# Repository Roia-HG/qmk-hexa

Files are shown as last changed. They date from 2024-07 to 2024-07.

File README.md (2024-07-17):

# qmk-hexa

 RP2040 칩을 사용한 멀티배열 스플릿 키보드

 3d 모델은 마그네틱 포고핀과 결합하는 구멍간격을 잘못 측정해서(데이터가 없었던 걸로 기억함) 개선이 필요함
그대로 사용하면 나처럼 한쪽을 약간 잘라서 사용해야하는 불상사가 일어남

 메인 오른쪽은 왼쪽 마그네틱 포고핀과 선을 연결하지 않음
양쪽 메인이 접속되면 row열 신호에 혼란이 발생하여 오류가 생길 것이기 때문에 스위치를 설치하는 것도 생각했지만
스위치를 설치할 적절한 방법이 떠오르지 않고 귀찮았으므로 연결하지 않고 사용하는 것으로 진행
즉, 메인 왼쪽은 네비키와 넘패드키 모두 좌우로 장착 가능하지만 메인 오른쪽은 오른쪽에만 장착 가능함.



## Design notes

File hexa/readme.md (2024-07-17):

# hexa

hexa

*A short description of the keyboard/project*

* Keyboard Maintainer: [Geon](https://github.com/Roia-HG)
* Hardware Supported: *The PCBs, controllers supported*
* Hardware Availability: *Links to where you can find this hardware*

Make example for this keyboard (after setting up your build environment):

    make hexa:default

Flashing example for this keyboard:

    make hexa:default:flash

See the [build environment setup](https://docs.qmk.fm/#/getting_started_build_tools) and the [make instructions](https://docs.qmk.fm/#/getting_started_make_guide) for more information. Brand new to QMK? Start with our [Complete Newbs Guide](https://docs.qmk.fm/#/newbs).

## Bootloader

Enter the bootloader in 3 ways:

* **Bootmagic reset**: Hold down the key at (0,0) in the matrix (usually the top left key or Escape) and plug in the keyboard
* **Physical reset button**: Briefly press the button on the back of the PCB - some may have pads you must short instead
* **Keycode in layout**: Press the key mapped to `QK_BOOT` if it is available

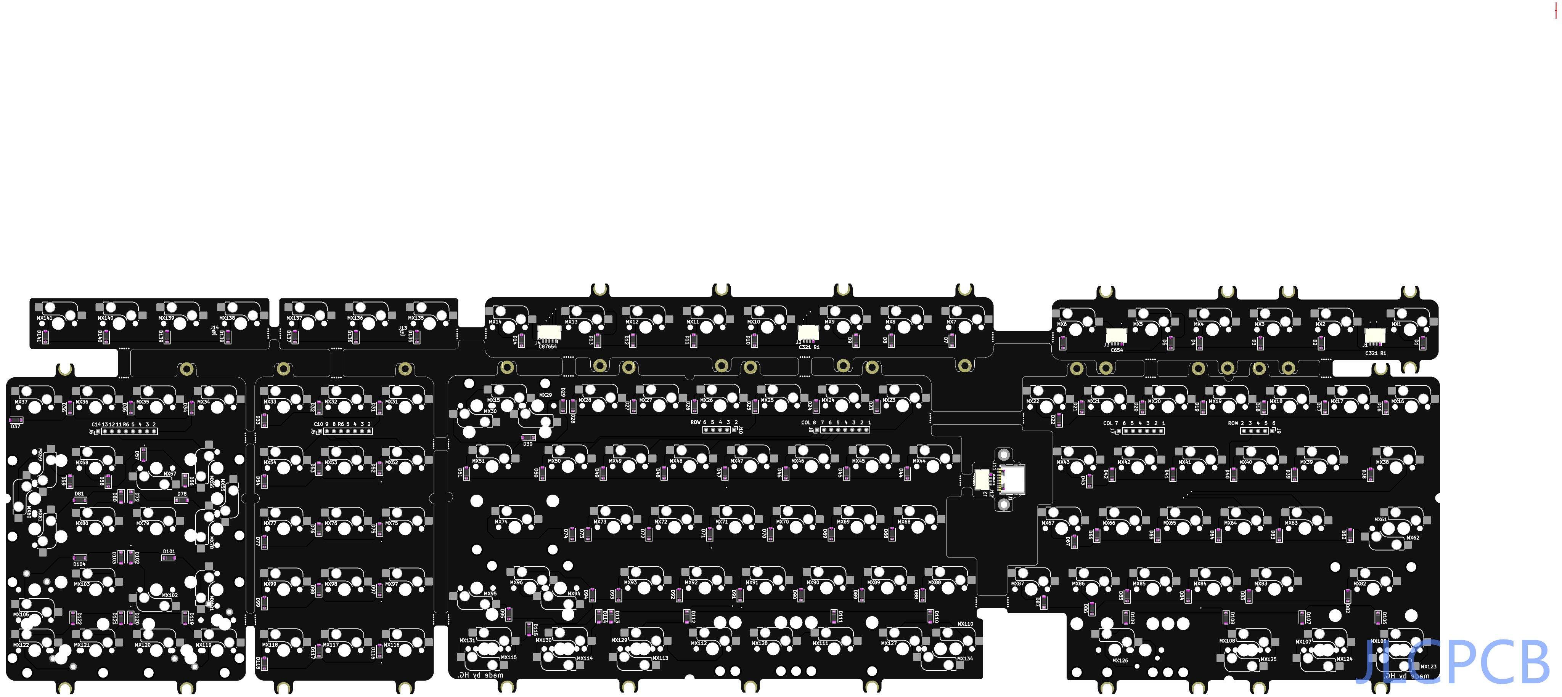
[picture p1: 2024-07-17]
capture-2024-05-31T09_20_14.196Z.png

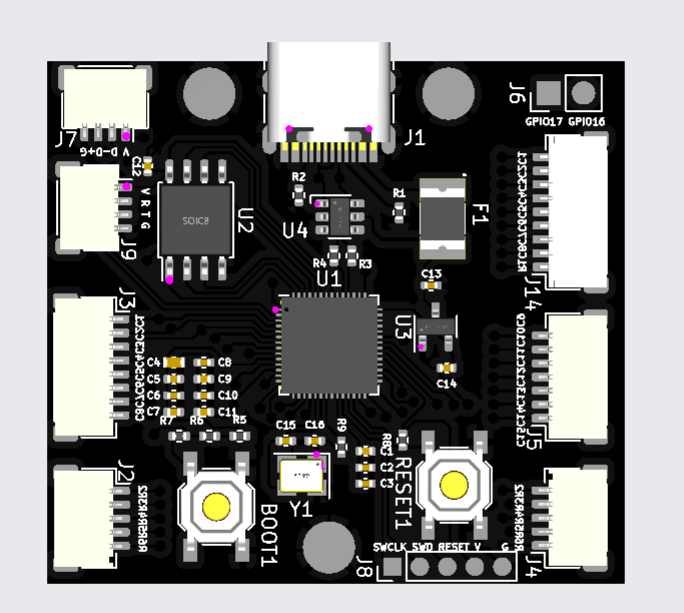
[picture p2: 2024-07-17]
pcba_picture_real.png

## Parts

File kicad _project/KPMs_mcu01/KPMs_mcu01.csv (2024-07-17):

Source: | D:\KeyboardMaking\A_PCB_kicad\Final\KPMs_mcu01\KPMs_mcu01.kicad_sch
Date: | 2024-05-22 오후 4:01:54
Tool: | Eeschema 7.0.6
Generator: | C:\Program Files\KiCad\7.0\bin\scripting\plugins/bom_csv_grouped_by_value.py
Component Count: | 43
Collated Components:
Item | Qty | Reference(s) | Value | LibPart | Footprint | Datasheet | DNP
1 | 2 | BOOT1, RESET1 | SW_Push | Switch:SW_Push | Button_Switch_SMD:SW_SPST_TL3342 | ~
2 | 5 | C1, C5, C12, C13, C14 | 1u | Device:C_Small | Capacitor_SMD:C_0402_1005Metric | ~
3 | 8 | C2, C3, C6, C7, C8, C9, C10, C11 | 100n | Device:C_Small | Capacitor_SMD:C_0402_1005Metric | ~
4 | 1 | C4 | 10u | Device:C_Small | Capacitor_SMD:C_0402_1005Metric | ~
5 | 2 | C15, C16 | 22p | Device:C_Small | Capacitor_SMD:C_0402_1005Metric | ~
6 | 1 | F1 | Fuse_Small | Device:Fuse_Small | Fuse:MF-MSMF050-2 | ~
7 | 1 | J1 | USB_C_Receptacle_USB2.0 | Connector:USB_C_Receptacle_USB2.0 | Connector_USB:USB_C_Receptacle_HRO_TYPE-C-31-M-12 | https://www.usb.org/sites/default/files/documents/usb_type-c.zip
8 | 2 | J2, J4 | Conn_01x05 | Connector_Generic:Conn_01x05 | Connector_JST:JST_SH_SM05B-SRSS-TB_1x05-1MP_P1.00mm_Horizontal | ~
9 | 1 | J3 | Conn_01x08 | Connector_Generic:Conn_01x08 | Connector_JST:JST_SH_SM08B-SRSS-TB_1x08-1MP_P1.00mm_Horizontal | ~
10 | 1 | J5 | Conn_01x07 | Connector_Generic:Conn_01x07 | Connector_JST:JST_SH_SM07B-SRSS-TB_1x07-1MP_P1.00mm_Horizontal | ~
11 | 1 | J6 | Conn_01x02 | Connector_Generic:Conn_01x02 | Connector_PinHeader_2.54mm:PinHeader_1x02_P2.54mm_Vertical | ~
12 | 2 | J7, J9 | Conn_01x04 | Connector_Generic:Conn_01x04 | Connector_JST:JST_SH_SM04B-SRSS-TB_1x04-1MP_P1.00mm_Horizontal | ~
13 | 1 | J8 | Conn_01x05 | Connector_Generic:Conn_01x05 | Connector_PinHeader_2.00mm:PinHeader_1x05_P2.00mm_Vertical | ~
14 | 1 | J14 | Conn_01x09 | Connector_Generic:Conn_01x09 | Connector_JST:JST_SH_SM09B-SRSS-TB_1x09-1MP_P1.00mm_Horizontal | ~
15 | 5 | R1, R2, R5, R6, R8 | 5.1k | Device:R_Small | Resistor_SMD:R_0402_1005Metric | ~
16 | 2 | R3, R4 | 27 | Device:R_Small | Resistor_SMD:R_0402_1005Metric | ~
17 | 2 | R7, R9 | 1k | Device:R_Small | Resistor_SMD:R_0402_1005Metric | ~
18 | 1 | U1 | RP2040 | MCU_RaspberryPi:RP2040 | Package_DFN_QFN:QFN-56-1EP_7x7mm_P0.4mm_EP3.2x3.2mm | https://datasheets.raspberrypi.com/rp2040/rp2040-datasheet.pdf
19 | 1 | U2 | W25Q128JVS | Memory_Flash:W25Q128JVS | Package_SO:SOIC-8_5.23x5.23mm_P1.27mm | http://www.winbond.com/resource-files/w25q128jv_dtr%20revc%2003272018%20plus.pdf
20 | 1 | U3 | XC6206PxxxMR | Regulator_Linear:XC6206PxxxMR | Package_TO_SOT_SMD:SOT-23-3 | https://www.torexsemi.com/file/xc6206/XC6206.pdf
21 | 1 | U4 | SRV05-4 | PCM_marbastlib-various:SRV05-4 | PCM_marbastlib-various:SOT-23-6-routable | http://www.onsemi.com/pub/Collateral/SRV05-4-D.PDF
22 | 1 | Y1 | Crystal_GND24 | Device:Crystal_GND24 | Crystal:Crystal_SMD_3225-4Pin_3.2x2.5mm | ~

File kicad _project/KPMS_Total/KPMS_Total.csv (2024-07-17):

Source: | D:\KeyboardMaking\A_PCB_kicad\Final\KPMS_Total\KPMS_Total.kicad_sch
Date: | 2024-05-31 ?�후 5:40:17
Tool: | Eeschema 7.0.6
Generator: | C:\Program Files\KiCad\7.0\bin\scripting\plugins/bom_csv_grouped_by_value_with_fp.py
Component Count: | 272
Designator | Qnty | Value | Cmp name | Footprint | Description | Vendor | DNP
D1, D2, D3, D4, D5, D6, D7, D8, D9, D10, D11, D12, D13, D14, D16, D17, D18, D19, D20, D21, D22, D23, D24, D25, D26, D27, D28, D29, D30, D31, D32, D33, D34, D35, D36, D37, D38, D39, D40, D41, D42, D43, D44, D45, D46, D47, D48, D49, D50, D51, D52, D53, D54, D56, D57, D58, D59, D62, D63, D64, D65, D66, D67, D68, D69, D70, D71, D72, D73, D74, D75, D76, D77, D78, D79, D80, D81, D82, D83, D84, D85, D86, D87, D88, D89, D90, D91, D92, D93, D94, D95, D97, D98, D99, D101, D102, D103, D104, D106, D107, D108, D109, D110, D111, D112, D113, D114, D115, D116, D117, D118, D119, D120, D121, D122, D135, D136, D137, D138, D139, D140, D141 | 122 | D_Small | D_Small | Diode_SMD:D_SOD-123 | Diode, small symbol
J1, J2, J3 | 3 | fn | Conn_01x04 | Connector_JST:JST_SH_SM04B-SRSS-TB_1x04-1MP_P1.00mm_Horizontal | Generic connector, single row, 01x04, script generated (kicad-library-utils/schlib/autogen/connector/)
J4 | 1 | fn | Conn_01x05 | Connector_JST:JST_SH_SM05B-SRSS-TB_1x05-1MP_P1.00mm_Horizontal | Generic connector, single row, 01x05, script generated (kicad-library-utils/schlib/autogen/connector/)
J5, J8 | 2 | Conn_01x08 | Conn_01x08 | magnetic_connector_pinhole:PinHeader_1x08_P2.20mm_Vertical | Generic connector, single row, 01x08, script generated (kicad-library-utils/schlib/autogen/connector/)
J6 | 1 | Conn_01x09 | Conn_01x09 | magnetic_connector_pinhole:PinHeader_1x09_P2.20mm_Vertical | Generic connector, single row, 01x09, script generated (kicad-library-utils/schlib/autogen/connector/)
J7 | 1 | Conn_01x07 | Conn_01x07 | magnetic_connector_pinhole:PinHeader_1x07_P2.20mm_Vertical | Generic connector, single row, 01x07, script generated (kicad-library-utils/schlib/autogen/connector/)
J9, J10 | 2 | Conn_01x05 | Conn_01x05 | magnetic_connector_pinhole:PinHeader_1x05_P2.20mm_Vertical | Generic connector, single row, 01x05, script generated (kicad-library-utils/schlib/autogen/connector/)
J11 | 1 | USB_C_Receptacle_USB2.0 | USB_C_Receptacle_USB2.0 | Connector_USB:USB_C_Receptacle_HRO_TYPE-C-31-M-12 | USB 2.0-only Type-C Receptacle connector
J12 | 1 | Conn_01x04 | Conn_01x04 | Connector_JST:JST_SH_SM04B-SRSS-TB_1x04-1MP_P1.00mm_Horizontal | Generic connector, single row, 01x04, script generated (kicad-library-utils/schlib/autogen/connector/)
J13, J14 | 2 | Conn_01x01 | Conn_01x01 | Connector_PinHeader_1.00mm:PinHeader_1x01_P1.00mm_Vertical | Generic connector, single row, 01x01, script generated (kicad-library-utils/schlib/autogen/connector/)
MX1, MX2, MX3, MX4, MX5, MX6, MX7, MX8, MX9, MX10, MX11, MX12, MX13, MX14, MX15, MX16, MX17, MX18, MX19, MX20, MX21, MX22, MX23, MX24, MX25, MX26, MX27, MX28, MX29, MX30, MX31, MX32, MX33, MX34, MX35, MX36, MX37, MX39, MX40, MX41, MX42, MX43, MX44, MX45, MX46, MX47, MX48, MX49, MX50, MX52, MX53, MX54, MX55, MX56, MX57, MX58, MX59, MX60, MX63, MX64, MX65, MX66, MX67, MX68, MX69, MX70, MX71, MX72, MX73, MX74, MX75, MX76, MX77, MX79, MX80, MX82, MX83, MX84, MX85, MX86, MX87, MX88, MX89, MX90, MX91, MX92, MX93, MX95, MX96, MX97, MX98, MX99, MX101, MX102, MX103, MX105, MX111, MX116, MX117, MX118, MX119, MX120, MX121, MX122, MX124, MX126, MX128, MX130, MX134, MX135, MX136, MX137, MX138, MX139, MX140, MX141 | 116 | MX_SW_HS | MX_SW_HS | PCM_marbastlib-mx:SW_MX_HS_1u | Push button switch, normally open, two pins, 45° tilted
MX38, MX51, MX123, MX125, MX127, MX129, MX131 | 7 | MX_SW_HS | MX_SW_HS | PCM_marbastlib-mx:SW_MX_HS_1.5u | Push button switch, normally open, two pins, 45° tilted
MX61 | 1 | MX_SW_HS | MX_SW_HS | PCM_marbastlib-mx:SW_MX_HS_1.75u_STP_1.25 | Push button switch, normally open, two pins, 45° tilted
MX62, MX94 | 2 | MX_SW_HS | MX_SW_HS | PCM_marbastlib-mx:SW_MX_HS_1.75u | Push button switch, normally open, two pins, 45° tilted
MX78, MX81 | 2 | MX_SW_HS | MX_SW_HS | PCM_marbastlib-mx:SW_MX_HS_1u_overlapkey | Push button switch, normally open, two pins, 45° tilted
MX106, MX107, MX108, MX110, MX112, MX113, MX114, MX115 | 8 | MX_SW_HS | MX_SW_HS | PCM_marbastlib-mx:SW_MX_HS_1.25u | Push button switch, normally open, two pins, 45° tilted

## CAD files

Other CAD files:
KPM_Total_plate01.dwg

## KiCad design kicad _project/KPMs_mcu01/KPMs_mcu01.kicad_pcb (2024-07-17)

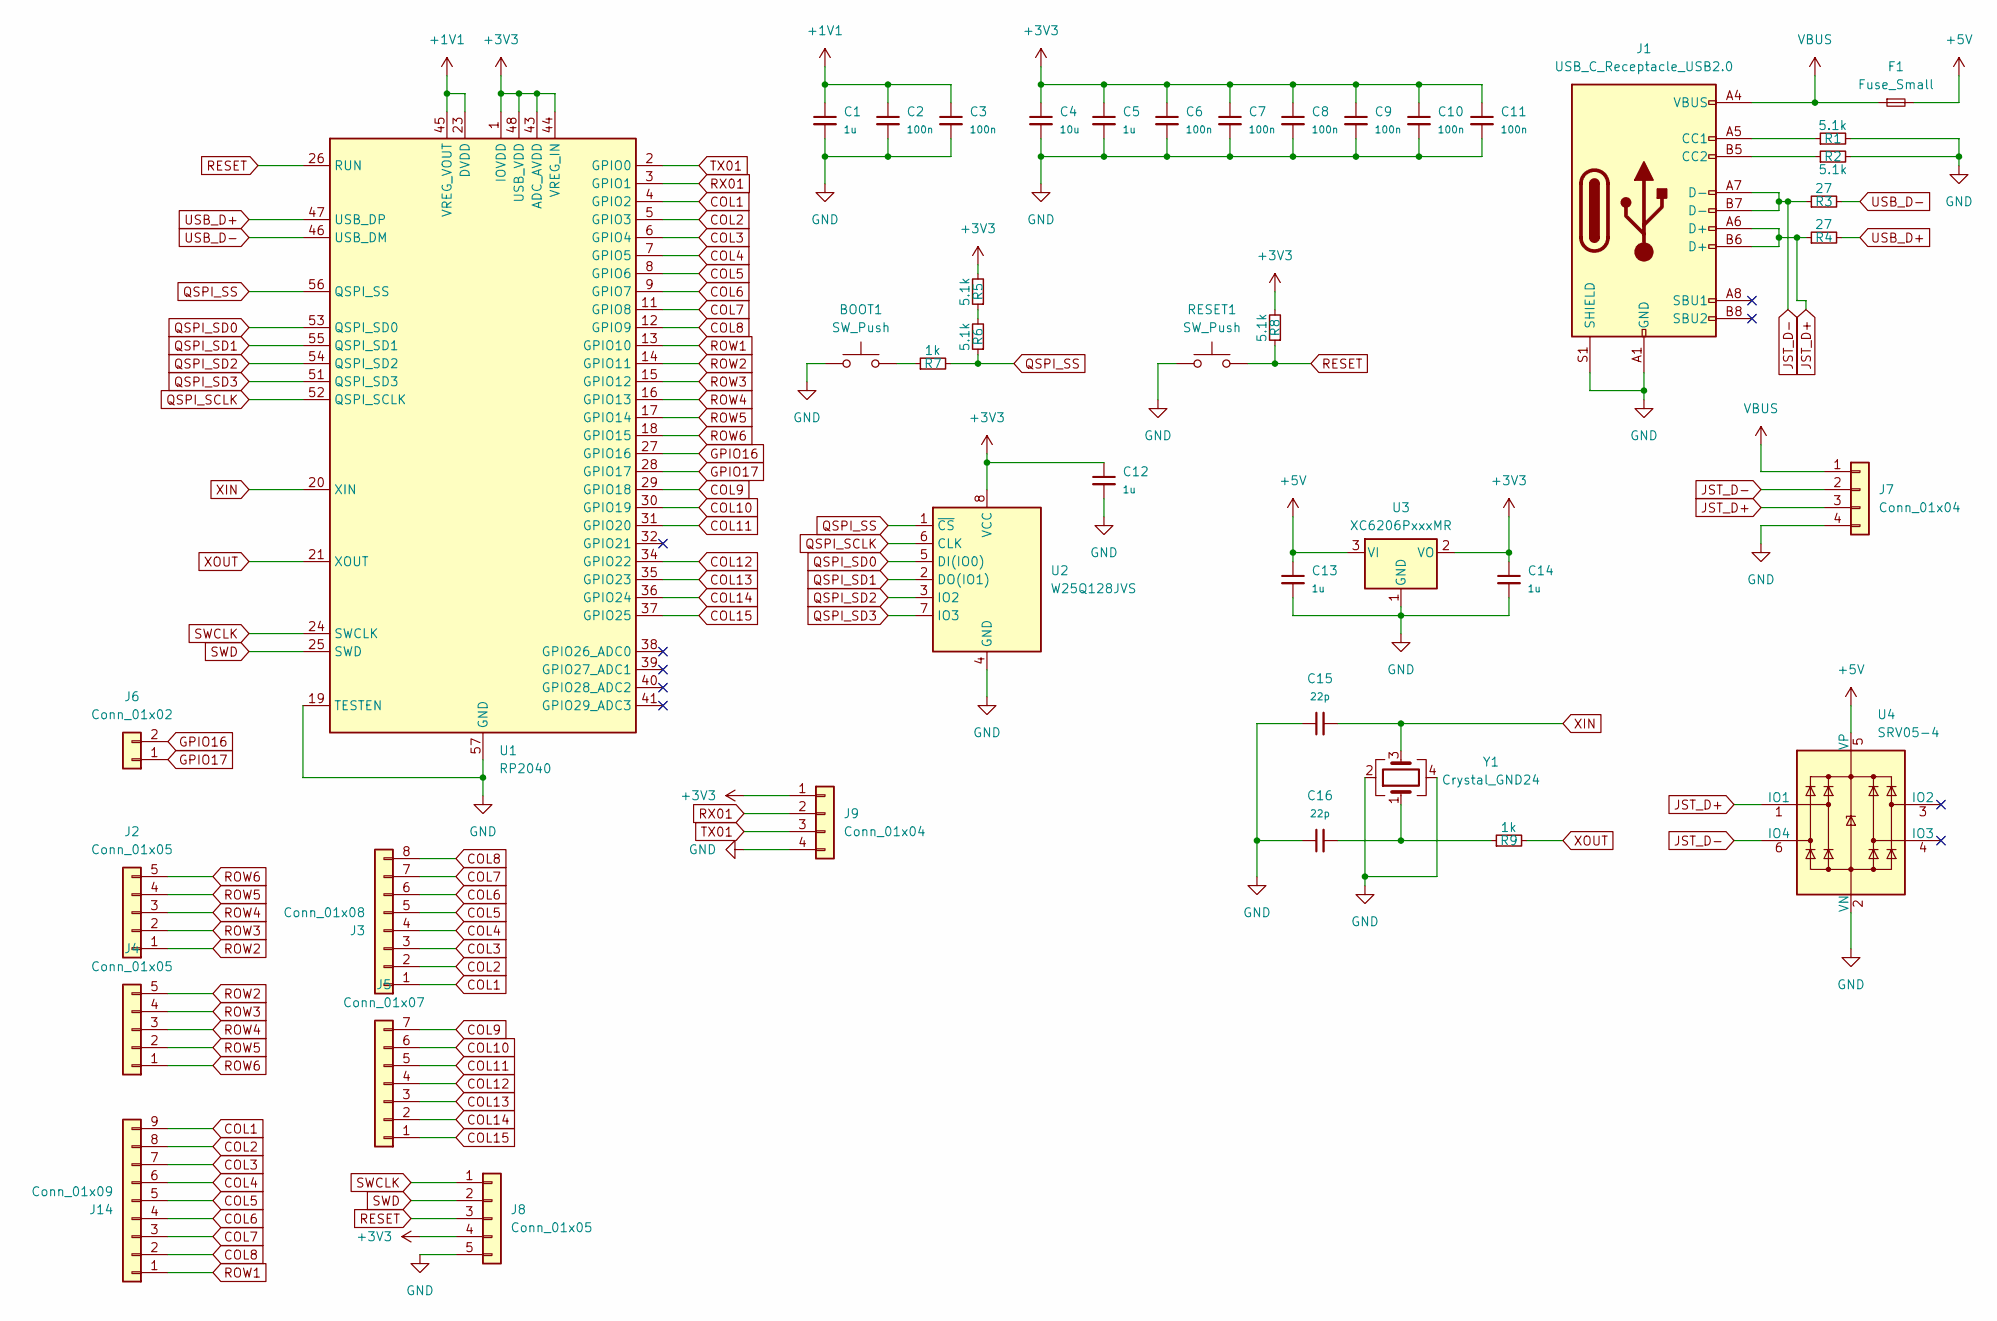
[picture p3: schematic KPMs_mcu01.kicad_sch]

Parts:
BOOT1: SW_Push; SW_SPST_TL3342
C1, C5, C12, C13, C14: 1u; C_0402_1005Metric
C2, C3, C6, C7, C8, C9, C10, C11: 100n; C_0402_1005Metric
C4: 10u; C_0402_1005Metric
C15, C16: 22p; C_0402_1005Metric
F1: Fuse_Small; MF-MSMF050-2
J1: USB_C_Receptacle_USB2.0; USB_C_Receptacle_HRO_TYPE-C-31-M-12
J2, J4: Conn_01x05; JST_SH_SM05B-SRSS-TB_1x05-1MP_P1.00mm_Horizontal
J3: Conn_01x08; JST_SH_SM08B-SRSS-TB_1x08-1MP_P1.00mm_Horizontal
J5: Conn_01x07; JST_SH_SM07B-SRSS-TB_1x07-1MP_P1.00mm_Horizontal
J6: Conn_01x02; PinHeader_1x02_P2.54mm_Vertical
J7, J9: Conn_01x04; JST_SH_SM04B-SRSS-TB_1x04-1MP_P1.00mm_Horizontal
J8: Conn_01x05; PinHeader_1x05_P2.00mm_Vertical
J14: Conn_01x09; JST_SH_SM09B-SRSS-TB_1x09-1MP_P1.00mm_Horizontal
R1, R2, R5, R6, R8: 5.1k; R_0402_1005Metric
R3, R4: 27; R_0402_1005Metric
R7, R9: 1k; R_0402_1005Metric
RESET1: SW_Push; SW_SPST_TL3342
U1: RP2040; QFN-56-1EP_7x7mm_P0.4mm_EP3.2x3.2mm
U2: W25Q128JVS; SOIC-8_5.23x5.23mm_P1.27mm
U3: XC6206PxxxMR; SOT-23-3
U4: SRV05-4; SOT-23-6-routable
Y1: Crystal_GND24; Crystal_SMD_3225-4Pin_3.2x2.5mm

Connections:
+1V1: C1.1, C2.1, C3.1, U1.23 (DVDD), U1.45 (VREG_VOUT), U1.50 (DVDD)
+3V3: C4.1, C5.1, C6.1, C7.1, C8.1, C9.1, C10.1, C11.1, C12.1, C14.1, J8.4, J9.1, R5.2, R8.2, U1.1 (IOVDD), U1.10 (IOVDD), U1.22 (IOVDD), U1.33 (IOVDD), U1.42 (IOVDD), U1.43 (ADC_AVDD), U1.44 (VREG_IN), U1.48 (USB_VDD), U1.49 (IOVDD), U2.8 (VCC), U3.2 (VO)
+5V: C13.1, F1.2, U3.3 (VI), U4.5 (VP)
COL1: J3.1, J14.9, U1.4 (GPIO2)
COL2: J3.2, J14.8, U1.5 (GPIO3)
COL3: J3.3, J14.7, U1.6 (GPIO4)
COL4: J3.4, J14.6, U1.7 (GPIO5)
COL5: J3.5, J14.5, U1.8 (GPIO6)
COL6: J3.6, J14.4, U1.9 (GPIO7)
COL7: J3.7, J14.3, U1.11 (GPIO8)
COL8: J3.8, J14.2, U1.12 (GPIO9)
COL9: J5.7, U1.29 (GPIO18)
COL10: J5.6, U1.30 (GPIO19)
COL11: J5.5, U1.31 (GPIO20)
COL12: J5.4, U1.34 (GPIO22)
COL13: J5.3, U1.35 (GPIO23)
COL14: J5.2, U1.36 (GPIO24)
COL15: J5.1, U1.37 (GPIO25)
GND: BOOT1.1, C1.2, C2.2, C3.2, C4.2, C5.2, C6.2, C7.2, C8.2, C9.2, C10.2, C11.2, C12.2, C13.2, C14.2, C15.1, C16.1, J1.A1 (GND), J1.A12 (GND), J1.B1 (GND), J1.B12 (GND), J1.S1 (SHIELD), J7.4, J8.5, J9.4, R1.2, R2.2, RESET1.1, U1.19 (TESTEN), U1.57 (GND), U2.4 (GND), U3.1 (GND), U4.2 (VN), Y1.2, Y1.4
GPIO16: J6.2, U1.27 (GPIO16)
GPIO17: J6.1, U1.28 (GPIO17)
JST_D+: J1.A6 (D+), J1.B6 (D+), J7.3, R4.1, U4.1 (IO1)
JST_D-: J1.A7 (D-), J1.B7 (D-), J7.2, R3.1, U4.6 (IO4)
unnamed: BOOT1.2, R7.1
unnamed: C16.2, R9.1, Y1.1
unnamed: J1.A5 (CC1), R1.1
unnamed: J1.B5 (CC2), R2.1
unnamed: R5.1, R6.2
QSPI_SCLK: U1.52 (QSPI_SCLK), U2.6 (CLK)
QSPI_SD0: U1.53 (QSPI_SD0), U2.5 (DI(IO0))
QSPI_SD1: U1.55 (QSPI_SD1), U2.2 (DO(IO1))
QSPI_SD2: U1.54 (QSPI_SD2), U2.3 (IO2)
QSPI_SD3: U1.51 (QSPI_SD3), U2.7 (IO3)
QSPI_SS: R6.1, R7.2, U1.56 (QSPI_SS), U2.1 (~CS)
RESET: J8.3, R8.1, RESET1.2, U1.26 (RUN)
ROW1: J14.1, U1.13 (GPIO10)
ROW2: J2.1, J4.5, U1.14 (GPIO11)
ROW3: J2.2, J4.4, U1.15 (GPIO12)
ROW4: J2.3, J4.3, U1.16 (GPIO13)
ROW5: J2.4, J4.2, U1.17 (GPIO14)
ROW6: J2.5, J4.1, U1.18 (GPIO15)
RX01: J9.2, U1.3 (GPIO1)
SWCLK: J8.1, U1.24 (SWCLK)
SWD: J8.2, U1.25 (SWD)
TX01: J9.3, U1.2 (GPIO0)
USB_D+: R4.2, U1.47 (USB_DP)
USB_D-: R3.2, U1.46 (USB_DM)
VBUS: F1.1, J1.A4 (VBUS), J1.A9 (VBUS), J1.B4 (VBUS), J1.B9 (VBUS), J7.1
XIN: C15.2, U1.20 (XIN), Y1.3
XOUT: R9.2, U1.21 (XOUT)

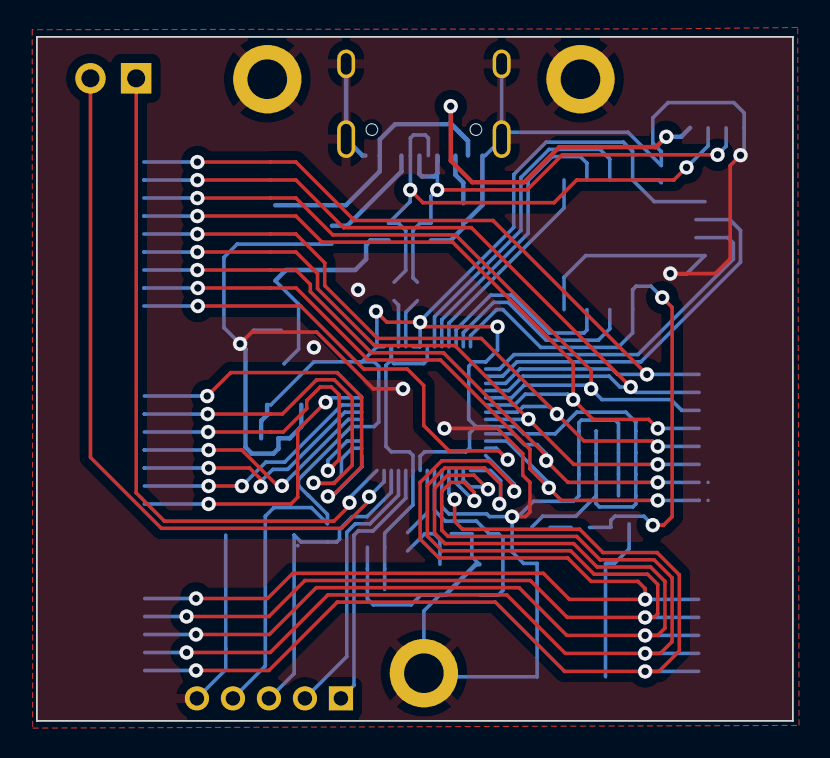
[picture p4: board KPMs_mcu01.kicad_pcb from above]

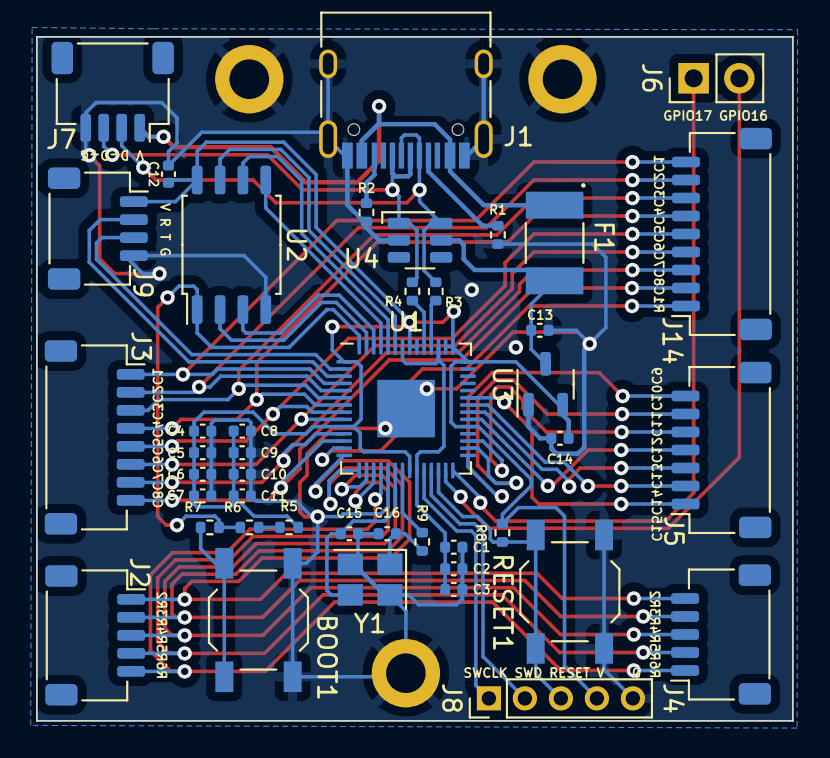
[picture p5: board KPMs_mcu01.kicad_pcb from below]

Board: 2 copper layers, 42.0 x 38.0 mm, 43 parts (43 on the bottom side), 50 nets.

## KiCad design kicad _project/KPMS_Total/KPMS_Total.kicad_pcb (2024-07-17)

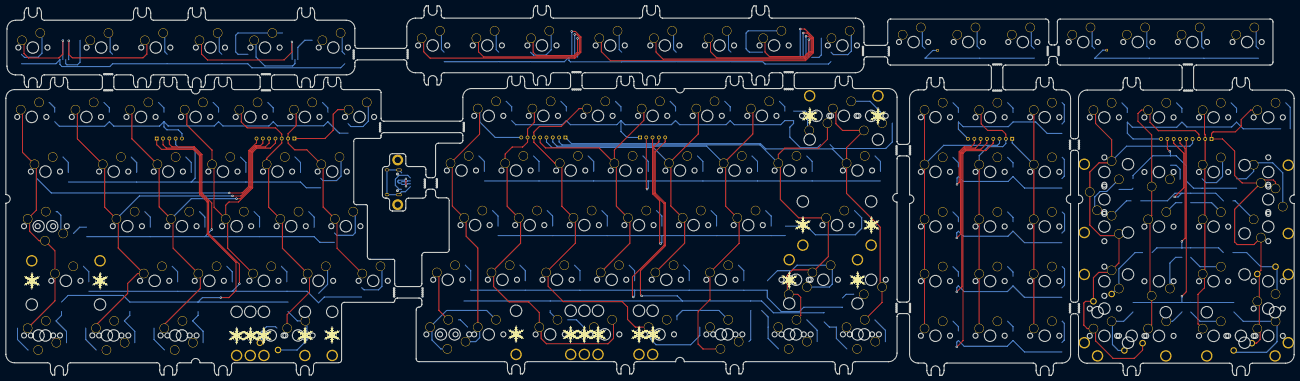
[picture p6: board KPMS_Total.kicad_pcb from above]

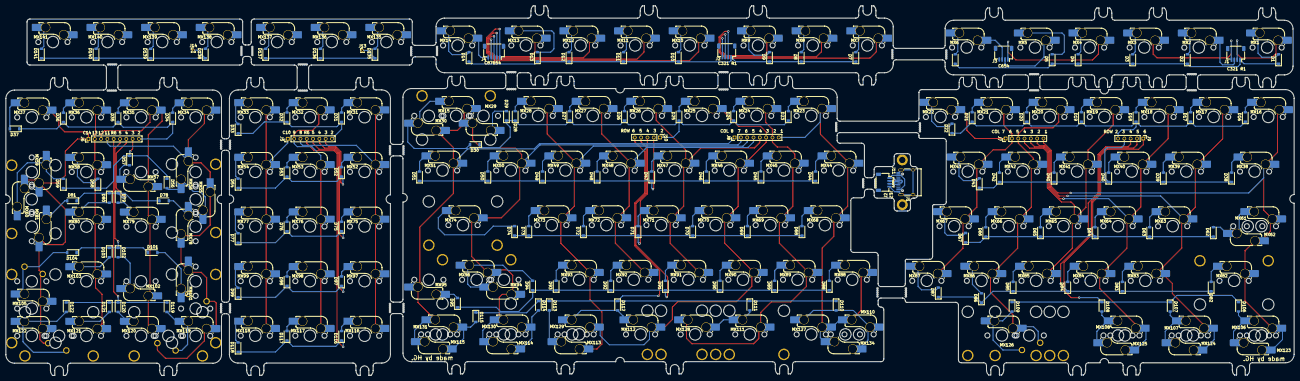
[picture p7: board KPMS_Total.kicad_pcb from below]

Board: 2 copper layers, 449.2 x 128.9 mm, 294 parts (290 on the bottom side), 186 nets.

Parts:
D1, D2, D3, D4, D5, D6, D7, D8, D9, D10, D11, D12, D13, D14, D16, D17, D18, D19, D20, D21, D22, D23, D24, D25, D26, D27, D28, D29, D30, D31, D32, D33, D34, D35, D36, D37, D38, D39, D40, D41, D42, D43, D44, D45, D46, D47, D48, D49, D50, D51, D52, D53, D54, D56, D57, D58, D59, D62, D63, D64, D65, D66, D67, D68, D69, D70, D71, D72, D73, D74, D75, D76, D77, D78, D79, D80, D81, D82, D83, D84, D85, D86, D87, D88, D89, D90, D91, D92, D93, D94, D95, D97, D98, D99, D101, D102, D103, D104, D106, D107, D108, D109, D110, D111, D112, D113, D114, D115, D116, D117, D118, D119, D120, D121, D122, D135, D136, D137, D138, D139, D140, D141: D_Small; D_SOD-123
J1, J2, J3: fn; JST_SH_SM04B-SRSS-TB_1x04-1MP_P1.00mm_Horizontal
J4: fn; JST_SH_SM05B-SRSS-TB_1x05-1MP_P1.00mm_Horizontal
J5, J8: Conn_01x08; PinHeader_1x08_P2.20mm_Vertical
J6: Conn_01x09; PinHeader_1x09_P2.20mm_Vertical
J7: Conn_01x07; PinHeader_1x07_P2.20mm_Vertical
J9, J10: Conn_01x05; PinHeader_1x05_P2.20mm_Vertical
J11: USB_C_Receptacle_USB2.0; USB_C_Receptacle_HRO_TYPE-C-31-M-12
J12: Conn_01x04; JST_SH_SM04B-SRSS-TB_1x04-1MP_P1.00mm_Horizontal
J13, J14: Conn_01x01; PinHeader_1x01_P1.00mm_Vertical
MX1, MX2, MX3, MX4, MX5, MX6, MX7, MX8, MX9, MX10, MX11, MX12, MX13, MX14, MX15, MX16, MX17, MX18, MX19, MX20, MX21, MX22, MX23, MX24, MX25, MX26, MX27, MX28, MX29, MX30, MX31, MX32, MX33, MX34, MX35, MX36, MX37, MX39, MX40, MX41, MX42, MX43, MX44, MX45, MX46, MX47, MX48, MX49, MX50, MX52, MX53, MX54, MX55, MX56, MX57, MX58, MX59, MX60, MX63, MX64, MX65, MX66, MX67, MX68, MX69, MX70, MX71, MX72, MX73, MX74, MX75, MX76, MX77, MX79, MX80, MX82, MX83, MX84, MX85, MX86, MX87, MX88, MX89, MX90, MX91, MX92, MX93, MX95, MX96, MX97, MX98, MX99, MX101, MX102, MX103, MX105, MX111, MX116, MX117, MX118, MX119, MX120, MX121, MX122, MX124, MX126, MX128, MX130, MX134, MX135, MX136, MX137, MX138, MX139, MX140, MX141: MX_SW_HS; SW_MX_HS_1u
MX38, MX51, MX123, MX125, MX127, MX129, MX131: MX_SW_HS; SW_MX_HS_1.5u
MX61: MX_SW_HS; SW_MX_HS_1.75u_STP_1.25
MX62, MX94: MX_SW_HS; SW_MX_HS_1.75u
MX78, MX81: MX_SW_HS; SW_MX_HS_1u_overlapkey
MX100, MX104, MX109, MX132, MX133: MX_SW_HS; SW_MX_1u
MX106, MX107, MX108, MX110, MX112, MX113, MX114, MX115: MX_SW_HS; SW_MX_HS_1.25u
S1, S9, S10, S11, S15, S16, S17: MX_stab; STAB_MX_P_2u
S2, S3, S5: MX_stab; STAB_MX_P_2.25u
S4, S6, S7, S8: MX_stab; STAB_MX_P_2.75u
S12: MX_stab; STAB_MX_P_7u_Left
S13: MX_stab; STAB_MX_P_6.25u_Right
S14: MX_stab; STAB_MX_P_7u_Right

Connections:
EXTRA_ROW1: D135.1 (K), D136.1 (K), D137.1 (K), J13.1
EXTRA_ROW2: D138.1 (K), D139.1 (K), D140.1 (K), D141.1 (K), J14.1
FnL_COL1: J1.2, MX1.1
FnL_COL2: J1.3, MX2.1
FnL_COL3: J1.4, MX3.1
FnL_COL4: J3.1, MX4.1
FnL_COL5: J3.2, MX5.1
FnL_COL6: J3.3, MX6.1
FnL_ROW1: D1.1 (K), D2.1 (K), D3.1 (K), D4.1 (K), D5.1 (K), D6.1 (K), J1.1
FnR_COL1: J2.2, MX7.1
FnR_COL2: J2.3, MX8.1
FnR_COL3: J2.4, MX9.1
FnR_COL4: J4.1, MX10.1
FnR_COL5: J4.2, MX11.1
FnR_COL6: J4.3, MX12.1
FnR_COL7: J4.4, MX13.1
FnR_COL8: J4.5, MX14.1
FnR_ROW1: D7.1 (K), D8.1 (K), D9.1 (K), D10.1 (K), D11.1 (K), D12.1 (K), D13.1 (K), D14.1 (K), J2.1
L_COL1: J7.7, MX16.1, MX38.1, MX61.1, MX62.2, MX82.1, MX106.1, MX123.2
L_COL2: J7.6, MX17.1, MX39.1, MX63.1, MX83.1, MX107.1, MX124.2
L_COL3: J7.5, MX18.1, MX40.1, MX64.1, MX84.1, MX108.1, MX125.2
L_COL4: J7.4, MX19.1, MX41.1, MX65.1, MX85.1
L_COL5: J7.3, MX20.1, MX42.1, MX66.1, MX86.1, MX109.1, MX126.1
L_COL6: J7.2, MX21.1, MX43.1, MX67.1, MX87.1
L_COL7: J7.1, MX22.1
L_ROW2: D16.1 (K), D17.1 (K), D18.1 (K), D19.1 (K), D20.1 (K), D21.1 (K), D22.1 (K), J9.5
L_ROW3: D38.1 (K), D39.1 (K), D40.1 (K), D41.1 (K), D42.1 (K), D43.1 (K), J9.4
L_ROW4: D62.1 (K), D63.1 (K), D64.1 (K), D65.1 (K), D66.1 (K), D67.1 (K), J9.3
L_ROW5: D82.1 (K), D83.1 (K), D84.1 (K), D85.1 (K), D86.1 (K), D87.1 (K), J9.2
L_ROW6: D106.1 (K), D107.1 (K), D108.1 (K), D109.1 (K), J9.1
NUM_COL11: J6.4, MX34.1, MX55.2, MX56.1, MX78.2, MX100.1, MX101.1, MX119.1, MX132.1
NUM_COL12: J6.3, MX35.1, MX57.2, MX79.1, MX102.2, MX120.1
NUM_COL13: J6.2, MX36.1, MX58.1, MX80.1, MX103.1, MX121.1
NUM_COL14: J6.1, MX37.1, MX59.1, MX60.1, MX81.1, MX104.1, MX105.1, MX122.1, MX133.1
NUM_ROW2: D34.1 (K), D35.1 (K), D36.1 (K), D37.1 (K), J6.9
NUM_ROW3: D56.1 (K), D57.1 (K), D58.1 (K), D59.1 (K), J6.8
NUM_ROW4: D78.1 (K), D79.1 (K), D80.1 (K), D81.1 (K), J6.7
NUM_ROW5: D101.1 (K), D102.1 (K), D103.1 (K), D104.1 (K), J6.6
NUM_ROW6: D119.1 (K), D120.1 (K), D121.1 (K), D122.1 (K), J6.5
unnamed: D1.2 (A), MX1.2
unnamed: D2.2 (A), MX2.2
unnamed: D3.2 (A), MX3.2
unnamed: D4.2 (A), MX4.2
unnamed: D5.2 (A), MX5.2
unnamed: D6.2 (A), MX6.2
unnamed: D7.2 (A), MX7.2
unnamed: D8.2 (A), MX8.2
unnamed: D9.2 (A), MX9.2
unnamed: D10.2 (A), MX10.2
unnamed: D11.2 (A), MX11.2
unnamed: D12.2 (A), MX12.2
unnamed: D13.2 (A), MX13.2
unnamed: D14.2 (A), MX14.2
unnamed: D16.2 (A), MX16.2
unnamed: D17.2 (A), MX17.2
unnamed: D18.2 (A), MX18.2
unnamed: D19.2 (A), MX19.2
unnamed: D20.2 (A), MX20.2
unnamed: D21.2 (A), MX21.2
unnamed: D22.2 (A), MX22.2
unnamed: D23.2 (A), MX23.2
unnamed: D24.2 (A), MX24.2
unnamed: D25.2 (A), MX25.2
unnamed: D26.2 (A), MX26.2
unnamed: D27.2 (A), MX27.2
unnamed: D28.2 (A), MX28.2
unnamed: D29.2 (A), MX29.2
unnamed: D30.2 (A), MX15.2, MX30.1
unnamed: D31.2 (A), MX31.2
unnamed: D32.2 (A), MX32.2
unnamed: D33.2 (A), MX33.2
unnamed: D34.2 (A), MX34.2
unnamed: D35.2 (A), MX35.2
unnamed: D36.2 (A), MX36.2
unnamed: D37.2 (A), MX37.2
unnamed: D38.2 (A), MX38.2
unnamed: D39.2 (A), MX39.2
unnamed: D40.2 (A), MX40.2
unnamed: D41.2 (A), MX41.2
unnamed: D42.2 (A), MX42.2
unnamed: D43.2 (A), MX43.2
unnamed: D44.2 (A), MX44.2
unnamed: D45.2 (A), MX45.2
unnamed: D46.2 (A), MX46.2
unnamed: D47.2 (A), MX47.2
unnamed: D48.2 (A), MX48.2
unnamed: D49.2 (A), MX49.2
unnamed: D50.2 (A), MX50.2
unnamed: D51.2 (A), MX51.2
unnamed: D52.2 (A), MX52.2
unnamed: D53.2 (A), MX53.2
unnamed: D54.2 (A), MX54.2
unnamed: D56.2 (A), MX55.1, MX56.2
unnamed: D57.2 (A), MX57.1
unnamed: D58.2 (A), MX58.2
unnamed: D59.2 (A), MX59.2, MX60.2
unnamed: D62.2 (A), MX61.2, MX62.1
unnamed: D63.2 (A), MX63.2
unnamed: D64.2 (A), MX64.2
unnamed: D65.2 (A), MX65.2
unnamed: D66.2 (A), MX66.2
unnamed: D67.2 (A), MX67.2
unnamed: D68.2 (A), MX68.2
unnamed: D69.2 (A), MX69.2
unnamed: D70.2 (A), MX70.2
unnamed: D71.2 (A), MX71.2
unnamed: D72.2 (A), MX72.2
unnamed: D73.2 (A), MX73.2
unnamed: D74.2 (A), MX74.2
unnamed: D75.2 (A), MX75.2
unnamed: D76.2 (A), MX76.2
unnamed: D77.2 (A), MX77.2
unnamed: D78.2 (A), MX78.1
unnamed: D79.2 (A), MX79.2
unnamed: D80.2 (A), MX80.2
unnamed: D81.2 (A), MX81.2
unnamed: D82.2 (A), MX82.2
unnamed: D83.2 (A), MX83.2
unnamed: D84.2 (A), MX84.2
unnamed: D85.2 (A), MX85.2
unnamed: D86.2 (A), MX86.2
unnamed: D87.2 (A), MX87.2
unnamed: D88.2 (A), MX88.2
unnamed: D89.2 (A), MX89.2
unnamed: D90.2 (A), MX90.2
unnamed: D91.2 (A), MX91.2
unnamed: D92.2 (A), MX92.2
unnamed: D93.2 (A), MX93.2
unnamed: D94.2 (A), MX94.1, MX96.2
unnamed: D95.2 (A), MX95.2
unnamed: D97.2 (A), MX97.2
unnamed: D98.2 (A), MX98.2
unnamed: D99.2 (A), MX99.2
unnamed: D101.2 (A), MX100.2, MX101.2
unnamed: D102.2 (A), MX102.1
unnamed: D103.2 (A), MX103.2
unnamed: D104.2 (A), MX104.2, MX105.2
unnamed: D106.2 (A), MX106.2, MX123.1
unnamed: D107.2 (A), MX107.2, MX124.1
unnamed: D108.2 (A), MX108.2, MX125.1
unnamed: D109.2 (A), MX109.2, MX126.2
unnamed: D110.2 (A), MX110.1, MX127.2, MX134.2
unnamed: D111.2 (A), MX111.2, MX128.1
unnamed: D112.2 (A), MX112.2, MX129.2
unnamed: D113.2 (A), MX113.1
unnamed: D114.2 (A), MX114.2, MX130.1
unnamed: D115.2 (A), MX115.2, MX131.1
unnamed: D116.2 (A), MX116.2
unnamed: D117.2 (A), MX117.2
unnamed: D118.2 (A), MX118.2
unnamed: D119.2 (A), MX119.2, MX132.2
unnamed: D120.2 (A), MX120.2
unnamed: D121.2 (A), MX121.2
unnamed: D122.2 (A), MX122.2, MX133.2
unnamed: D135.2 (A), MX135.2
unnamed: D136.2 (A), MX136.2
unnamed: D137.2 (A), MX137.2
unnamed: D138.2 (A), MX138.2
unnamed: D139.2 (A), MX139.2
unnamed: D140.2 (A), MX140.2
unnamed: D141.2 (A), MX141.2
unnamed: J11.A1 (GND), J11.A12 (GND), J11.B1 (GND), J11.B12 (GND), J11.S1 (SHIELD), J12.4
unnamed: J11.A4 (VBUS), J11.A9 (VBUS), J11.B4 (VBUS), J11.B9 (VBUS), J12.1
unnamed: J11.A7 (D-), J11.B7 (D-), J12.2
unnamed: J11.A6 (D+), J11.B6 (D+), J12.3
R_COL1: J8.8, MX23.1, MX44.1, MX68.1, MX88.1, MX110.2, MX127.1, MX134.1
R_COL2: J8.7, MX24.1, MX45.1, MX69.1, MX89.1, MX111.1, MX128.2
R_COL3: J8.6, MX25.1, MX46.1, MX70.1, MX90.1, MX112.1, MX129.1
R_COL4: J8.5, MX26.1, MX47.1, MX71.1, MX91.1
R_COL5: J8.4, MX27.1, MX48.1, MX72.1, MX92.1
R_COL6: J8.3, MX28.1, MX49.1, MX73.1, MX93.1, MX113.2
R_COL7: J8.2, MX29.1, MX50.1, MX74.1, MX94.2, MX96.1, MX114.1, MX130.2
R_COL8: J8.1, MX15.1, MX30.2, MX51.1, MX95.1, MX115.1, MX131.2
R_ROW2: D23.1 (K), D24.1 (K), D25.1 (K), D26.1 (K), D27.1 (K), D28.1 (K), D29.1 (K), D30.1 (K), J10.1
R_ROW3: D44.1 (K), D45.1 (K), D46.1 (K), D47.1 (K), D48.1 (K), D49.1 (K), D50.1 (K), D51.1 (K), J10.2
R_ROW4: D68.1 (K), D69.1 (K), D70.1 (K), D71.1 (K), D72.1 (K), D73.1 (K), D74.1 (K), J10.3
R_ROW5: D88.1 (K), D89.1 (K), D90.1 (K), D91.1 (K), D92.1 (K), D93.1 (K), D94.1 (K), D95.1 (K), J10.4
R_ROW6: D110.1 (K), D111.1 (K), D112.1 (K), D113.1 (K), D114.1 (K), D115.1 (K), J10.5
navi_COL8: J5.3, MX31.1, MX52.1, MX75.1, MX97.1, MX116.1
navi_COL9: J5.2, MX32.1, MX53.1, MX76.1, MX98.1, MX117.1
navi_COL10: J5.1, MX33.1, MX54.1, MX77.1, MX99.1, MX118.1
navi_ROW2: D31.1 (K), D32.1 (K), D33.1 (K), J5.8
navi_ROW3: D52.1 (K), D53.1 (K), D54.1 (K), J5.7
navi_ROW4: D75.1 (K), D76.1 (K), D77.1 (K), J5.6
navi_ROW5: D97.1 (K), D98.1 (K), D99.1 (K), J5.5
navi_ROW6: D116.1 (K), D117.1 (K), D118.1 (K), J5.4

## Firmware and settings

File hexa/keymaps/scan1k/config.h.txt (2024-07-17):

#ifndef CONFIG_H
#define CONFIG_H

#define MASTER_LEFT
#define SPLIT_USE_DETECT

/* Change USB Polling Rate to 1000hz and a larger keys per scan for elite gaming*/
#define USB_POLLING_INTERVAL_MS 1
#define QMK_KEYS_PER_SCAN 12

#endif
